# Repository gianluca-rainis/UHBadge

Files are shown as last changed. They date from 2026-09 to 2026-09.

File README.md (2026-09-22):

# UHBadge





View PCB (https://kicanvas.org/?repo=https://github.com/gianluca-rainis/UHBadge)

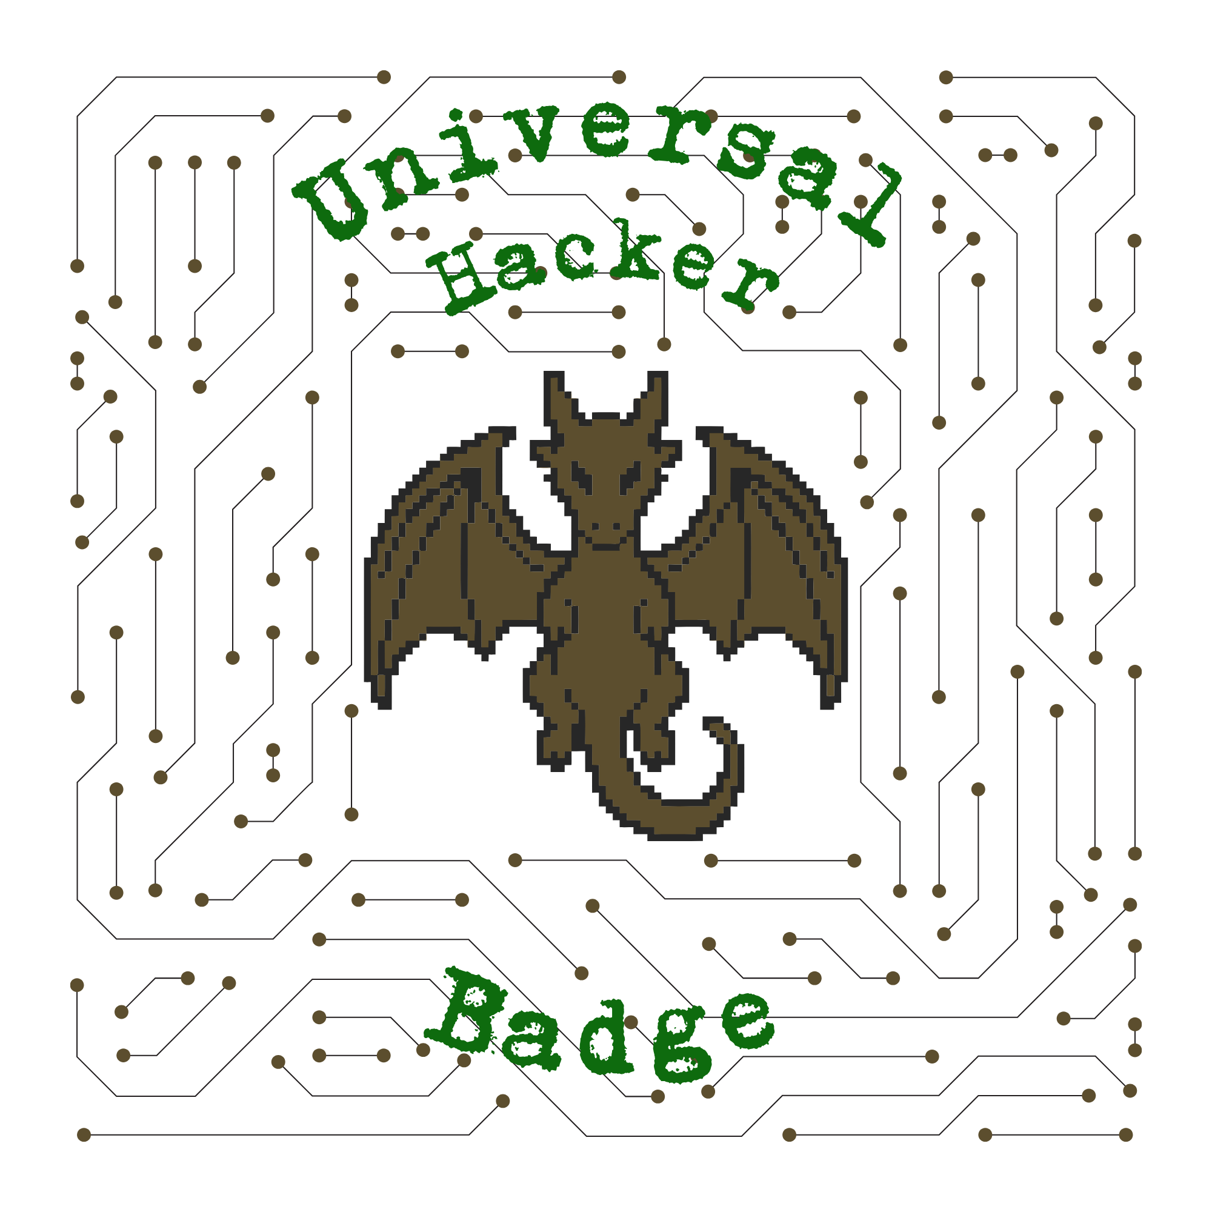
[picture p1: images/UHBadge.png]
UHBadge Logo


Universal Hacker Badge - The ultimate badge for hackers.

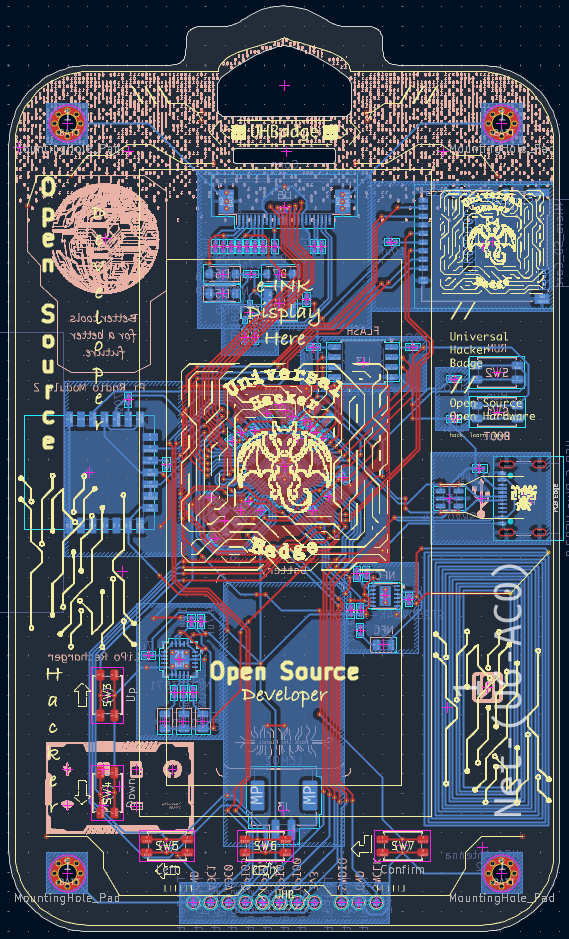
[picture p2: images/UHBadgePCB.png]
UHBadge PCB Image


## Author
The author of the whole project is: 
**Gianluca Rainis** - [gianluca-rainis](https://github.com/gianluca-rainis) on GitHub.

## License
### Hardware design files (schematics, PCB, BOM):
Licensed under [CERN-OHL-S v2.0](LICENSE-CERN-OHL-S.md)

### Software, firmware and documentation:
Licensed under the [MIT License](LICENSE-MIT.md)

## AI Disclaimer
**No AI was used in the conception, design, or engineering of the hardware.**
Every circuit and every design decision are the original work of the author.

*AI tools* were used as **writing assistants** for parts of the firmware, to help write technical drivers and low-level functions.
**All content has been reviewed, verified, and edited by the author.**

## Development Tools
- **PCB Design:** KiCad
- **Documentation and code:** Visual Studio Code

## PCB Manufacturing
The Gerber files for PCB manufacturing are available in the [`gerber/`](gerber/) directory.

## Project Structure
```
UHBadge/
├── CustomFootprints.pretty/  # Custom footprints
├── firmware/                 # The RP2350 firmware
├── gerber/                   # PCB manufacturing files (Gerber format)
├── images/                   # Documentation images
├── .gitattributes            # Gitattributes file
├── .gitignore                # Gitignore file
├── gerber.zip                # Zip folder with all the gerber files
├── UHBadge.kicad_pcb         # PCB layout file
├── UHBadge.kicad_pro         # KiCad project file
├── UHBadge.kicad_sch         # Schematic file
├── UHBadge.step              # 3D model
├── BOM.csv                   # Bill Of Materials
├── LICENSE-CERN-OHL-S.md     # CERN-OHL-S License
├── LICENSE-MIT.md            # MIT License
└── README.md                 # This file
```

## Technical Details
- **Size**: 70mm x 117.6mm
- **Layers**: 2
- **Supply Voltage**: 3v3

## Build the firmware
From the directory of the repo:
```bash
cd firmware/build

cmake ..
make -j$(sysctl -n hw.ncpu)
```

You'll find the `UHBadge.uf2` file in the `firmware/build` directory.

## Hardware
### Schematic
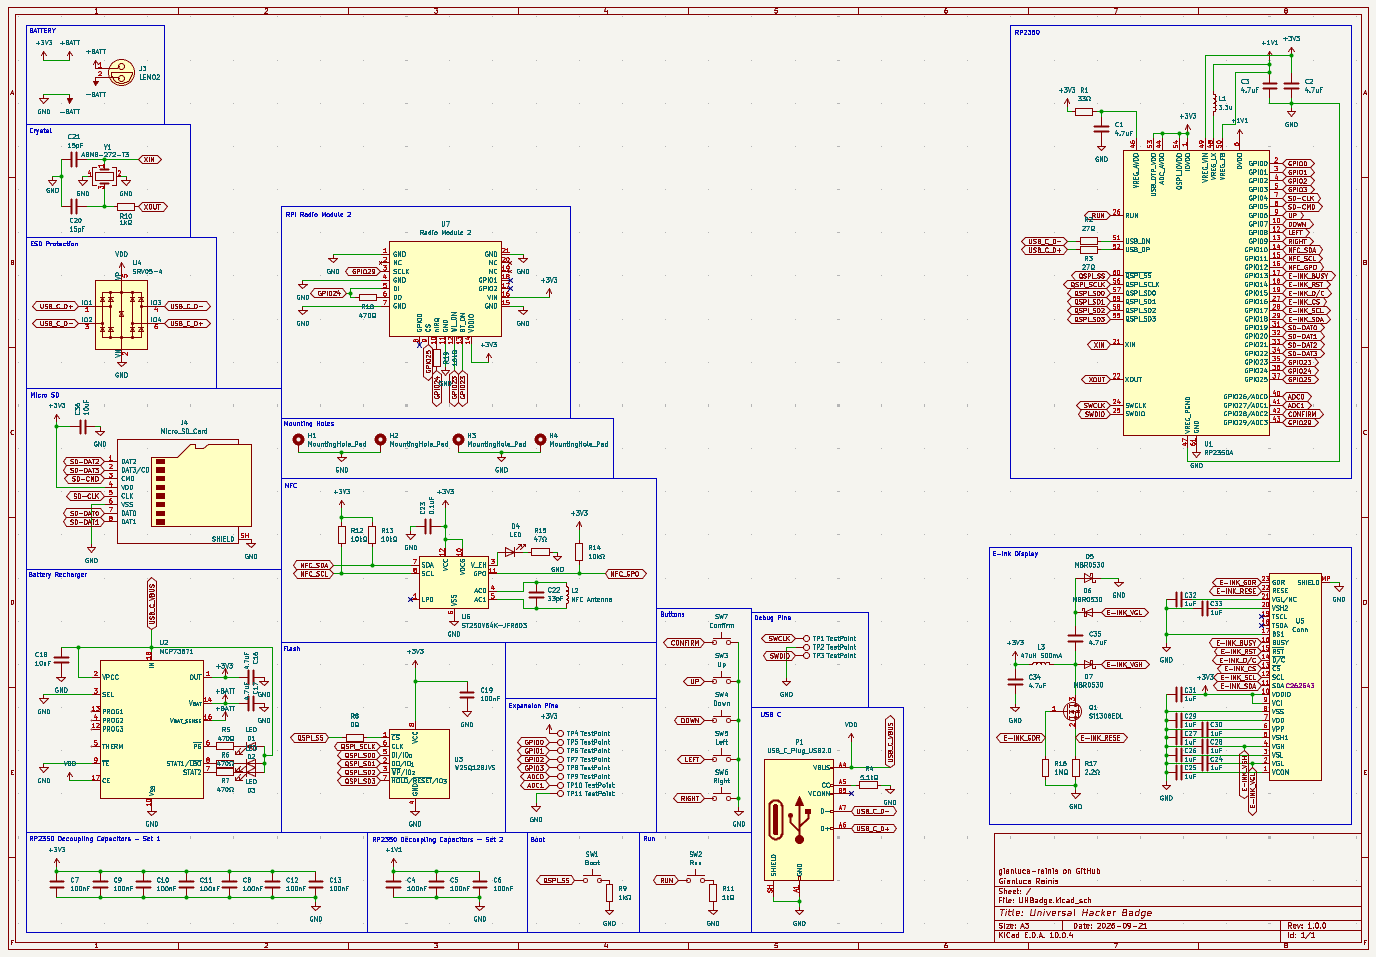
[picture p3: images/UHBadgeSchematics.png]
UHBadge Schematics


### PCB
UHBadge PCB Image

### 3D Render
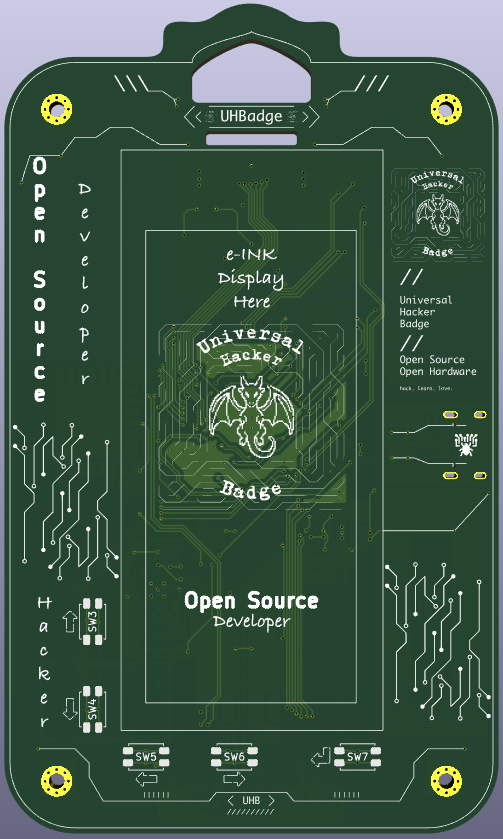
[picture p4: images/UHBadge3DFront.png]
UHBadge Render Front

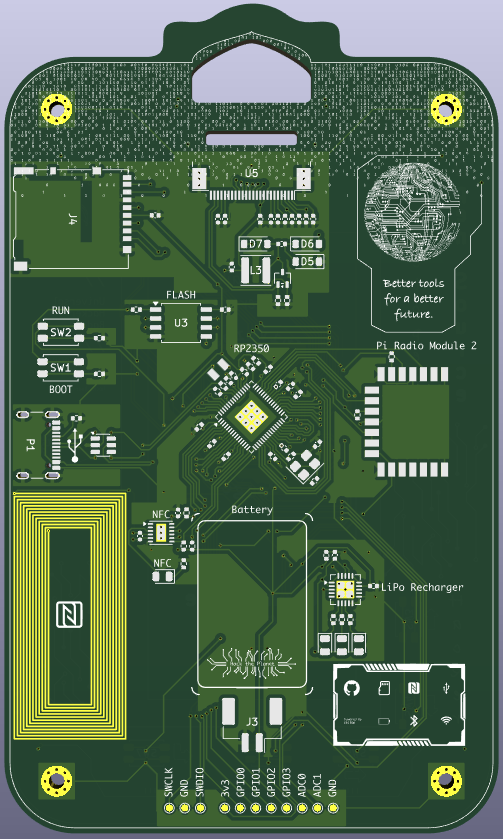
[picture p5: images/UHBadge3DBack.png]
UHBadge Render Back


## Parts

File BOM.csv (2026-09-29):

Reference | Quantity | Value | Footprint | Total Price | LCSC Part
C1,C2,C3,C16,C17,C34,C35 | 7 | 4.7uF | Capacitor_SMD:C_0402_1005Metric | $0.85 | C368809
C4,C5,C6,C7,C8,C9,C10,C11,C12,C13,C19 | 11 | 100nF | Capacitor_SMD:C_0402_1005Metric | $0.46 | C1525
C18,C36 | 2 | 10uF | Capacitor_SMD:C_0402_1005Metric | $0.65 | C315248
C20,C21 | 2 | 15pF | Capacitor_SMD:C_0402_1005Metric | $0.36 | C1548
C22 | 1 | 33pF | Capacitor_SMD:C_0402_1005Metric | $0.43 | C70465
C23 | 1 | 0.1uF | Capacitor_SMD:C_0402_1005Metric | $0.46 | C1525
C24,C25,C26,C27,C28,C29,C30,C31,C32,C33 | 10 | 1uF | Capacitor_SMD:C_0402_1005Metric | $0.50 | C52923
D1,D2,D3,D4 | 4 | LED | LED_SMD:LED_0805_2012Metric | $0.50 | C25170728
D5,D6,D7 | 3 | MBR0530 | Diode_SMD:D_SOD-123 | $0.89 | C725477
J3 | 1 | LEMO2 | Connector_Molex:Molex_CLIK-Mate_502494-0270_1x02-1MP_P2.00mm_Horizontal | $0.56 | C587928
J4 | 1 | Micro_SD_Card | Connector_Card:microSD_HC_Hirose_DM3AT-SF-PEJM5 | $1.79 | C114218
L1 | 1 | 3.3u | CustomFootprints:Inductor | $1.43 | C42411119
L3 | 1 | 47uH 500mA | Inductor_SMD:L_APV_ANR4018 | $0.79 | C167808
P1 | 1 | USB_C_Plug_USB2.0 | Connector_USB:USB_C_Receptacle_GCT_USB4105-xx-A_16P_TopMnt_Horizontal | $1.31 | C3020560
Q1 | 1 | Si1308EDL | Package_TO_SOT_SMD:SOT-323_SC-70 | $0.43 | C7603347
R1 | 1 | 33Ω | Resistor_SMD:R_0402_1005Metric | $0.18 | C453643
R2,R3 | 2 | 27Ω | Resistor_SMD:R_0402_1005Metric | $0.20 | C2909343
R4 | 1 | 5.1kΩ | Resistor_SMD:R_0402_1005Metric | $0.19 | C2906874
R5,R6,R7,R18 | 4 | 470Ω | Resistor_SMD:R_0402_1005Metric | $0.26 | C25117
R8 | 1 | 0Ω | Resistor_SMD:R_0402_1005Metric | $0.36 | C106231
R9,R10,R11 | 3 | 1kΩ | Resistor_SMD:R_0402_1005Metric | $0.22 | C11702
R12,R13,R14,R19 | 4 | 10kΩ | Resistor_SMD:R_0402_1005Metric | $0.19 | C71617
R15 | 1 | 47Ω | Resistor_SMD:R_0402_1005Metric | $0.18 | C2909362
R16 | 1 | 1MΩ | Resistor_SMD:R_0402_1005Metric | $0.26 | C93949
R17 | 1 | 2.2Ω | Resistor_SMD:R_0402_1005Metric | $0.20 | C2906903
SW1 | 1 | Boot | Button_Switch_SMD:SW_SPST_EVQP2_MiddlePushTravel_H2.5mm | $0.29 | C2915174
SW2 | 1 | Run | Button_Switch_SMD:SW_SPST_EVQP2_MiddlePushTravel_H2.5mm | $0.29 | C2915174
SW3 | 1 | Up | Button_Switch_SMD:SW_SPST_EVQP2_MiddlePushTravel_H2.5mm | $0.29 | C2915174
SW4 | 1 | Down | Button_Switch_SMD:SW_SPST_EVQP2_MiddlePushTravel_H2.5mm | $0.29 | C2915174
SW5 | 1 | Left | Button_Switch_SMD:SW_SPST_EVQP2_MiddlePushTravel_H2.5mm | $0.29 | C2915174
SW6 | 1 | Right | Button_Switch_SMD:SW_SPST_EVQP2_MiddlePushTravel_H2.5mm | $0.29 | C2915174
SW7 | 1 | Confirm | Button_Switch_SMD:SW_SPST_EVQP2_MiddlePushTravel_H2.5mm | $0.29 | C2915174
U1 | 1 | RP2350A | Package_DFN_QFN:QFN-60-1EP_7x7mm_P0.4mm_EP3.4x3.4mm | $1.30 | C42411118
U2 | 1 | MCP73871 | Package_DFN_QFN:QFN-20-1EP_4x4mm_P0.5mm_EP2.5x2.5mm | $2.20 | C511310
U3 | 1 | W25Q128JVS | Package_SO:SOIC-8_5.3x5.3mm_P1.27mm | $2.53 | C113767
U4 | 1 | SRV05-4 | Package_TO_SOT_SMD:SOT-23-6 | $0.56 | C2836319
U5 | 1 | Conn | Connector_FFC-FPC:Jushuo_AFC07-S24FCA-00_1x24-1MP_P0.50_Horizontal | $0.66 | C262567
U6 | 1 | ST25DV64K-JFR6D3 | Package_DFN_QFN:ST_UFDFPN-12-1EP_3x3mm_P0.5mm_EP1.4x2.55mm | $2.11 | C2654868
U7 | 1 | Radio Module 2 | CustomFootprints:rpi_rmc20452t | 4.20€ (~ $4.76) | https://www.reichelt.com/it/it/shop/prodotto/raspberry_pi_-_modulo_radio_rmc20452t-407167
Y1 | 1 | ABM8-272-T3 | Crystal:Crystal_SMD_3225-4Pin_3.2x2.5mm | $0.32 | C19270184
e-ink display | 1 |  |  | 9.39€ (~ $10.64) | https://it.aliexpress.com/item/1005012065049246.html
Li-Po battery | 1 |  |  | 7.44€ (~ $8.43) | https://it.aliexpress.com/item/1005007341161722.html
Total | $49.19

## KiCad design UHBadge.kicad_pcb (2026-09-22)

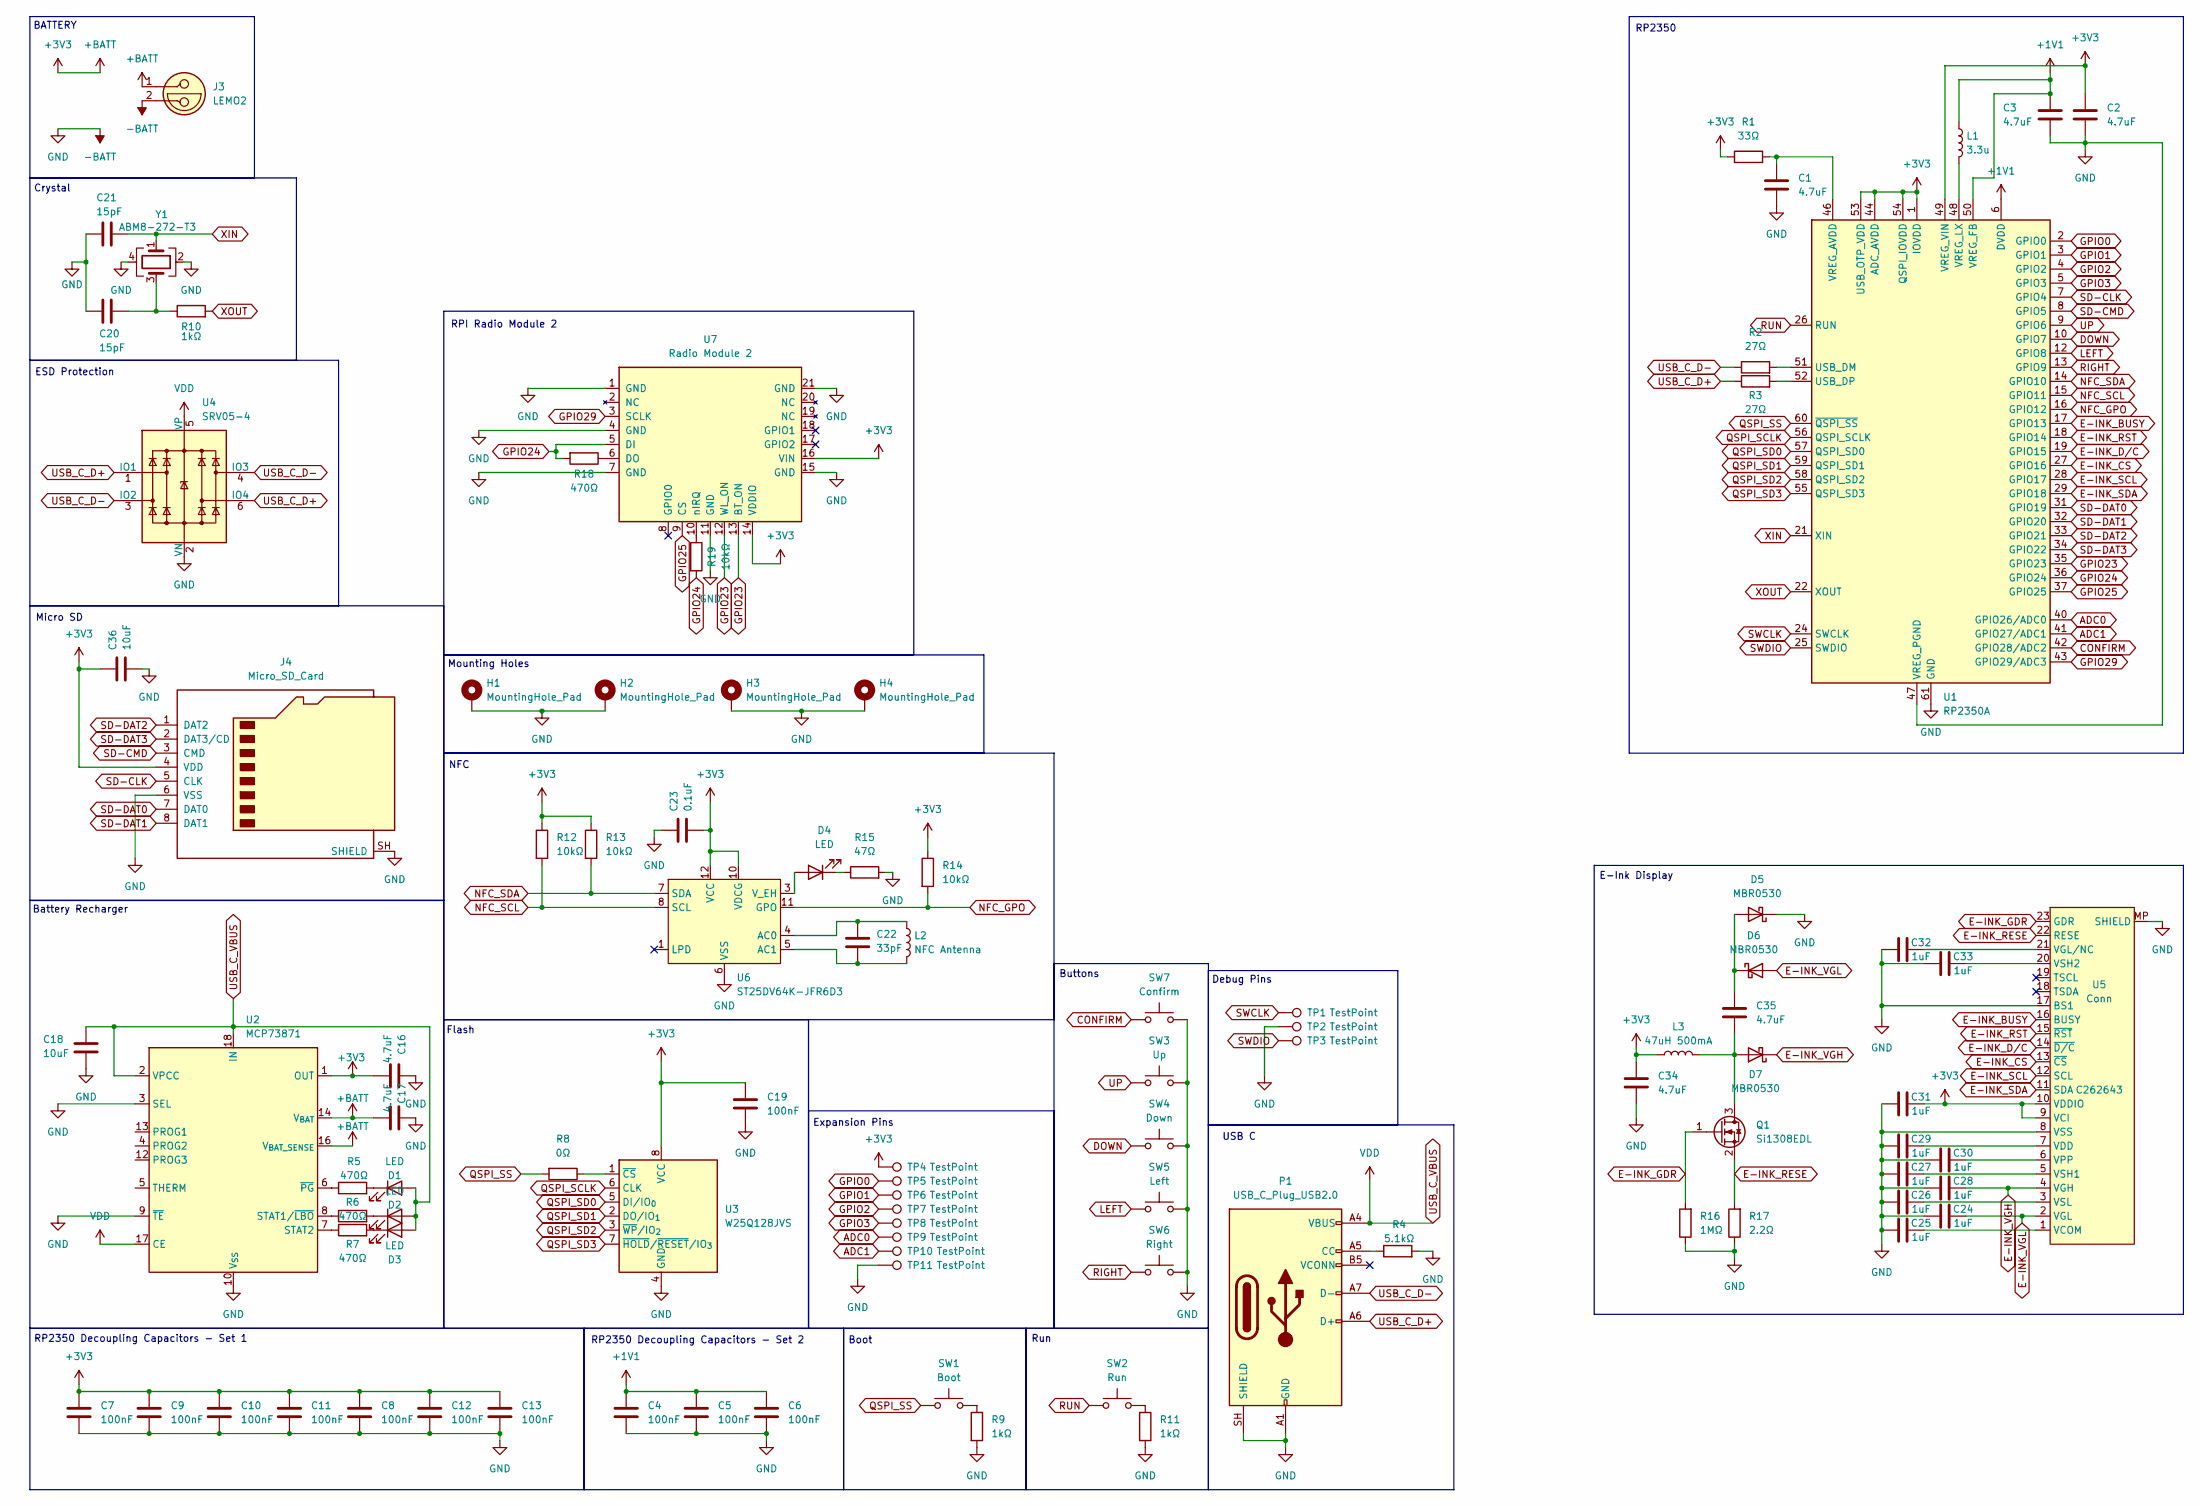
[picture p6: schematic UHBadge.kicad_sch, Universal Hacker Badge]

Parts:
C1, C2, C3, C16, C17, C34, C35: 4.7uF; C_0402_1005Metric
C4, C5, C6, C7, C8, C9, C10, C11, C12, C13, C19: 100nF; C_0402_1005Metric
C18, C36: 10uF; C_0402_1005Metric
C20, C21: 15pF; C_0402_1005Metric
C22: 33pF; C_0402_1005Metric
C23: 0.1uF; C_0402_1005Metric
C24, C25, C26, C27, C28, C29, C30, C31, C32, C33: 1uF; C_0402_1005Metric
D1, D2, D3, D4: LED; LED_0805_2012Metric
D5, D6, D7: MBR0530; D_SOD-123
H1, H2, H3, H4: MountingHole_Pad; MountingHole_2.2mm_M2_Pad_Via
J3: LEMO2; Molex_CLIK-Mate_502494-0270_1x02-1MP_P2.00mm_Horizontal
J4: Micro_SD_Card; microSD_HC_Hirose_DM3AT-SF-PEJM5
L1: 3.3u; Inductor
L2: NFC Antenna; NFC_Antenna
L3: 47uH 500mA; L_APV_ANR4018
P1: USB_C_Plug_USB2.0; USB_C_Receptacle_GCT_USB4105-xx-A_16P_TopMnt_Horizontal
Q1: Si1308EDL; SOT-323_SC-70
R1: 33Ω; R_0402_1005Metric
R2, R3: 27Ω; R_0402_1005Metric
R4: 5.1kΩ; R_0402_1005Metric
R5, R6, R7, R18: 470Ω; R_0402_1005Metric
R8: 0Ω; R_0402_1005Metric
R9, R10, R11: 1kΩ; R_0402_1005Metric
R12, R13, R14, R19: 10kΩ; R_0402_1005Metric
R15: 47Ω; R_0402_1005Metric
R16: 1MΩ; R_0402_1005Metric
R17: 2.2Ω; R_0402_1005Metric
SW1: Boot; SW_SPST_EVQP2_MiddlePushTravel_H2.5mm
SW2: Run; SW_SPST_EVQP2_MiddlePushTravel_H2.5mm
SW3: Up; SW_SPST_EVQP2_MiddlePushTravel_H2.5mm
SW4: Down; SW_SPST_EVQP2_MiddlePushTravel_H2.5mm
SW5: Left; SW_SPST_EVQP2_MiddlePushTravel_H2.5mm
SW6: Right; SW_SPST_EVQP2_MiddlePushTravel_H2.5mm
SW7: Confirm; SW_SPST_EVQP2_MiddlePushTravel_H2.5mm
TP1, TP2, TP3, TP4, TP5, TP6, TP7, TP8, TP9, TP10, TP11: TestPoint; TestPoint_Pad_D1.0mm
U1: RP2350A; QFN-60-1EP_7x7mm_P0.4mm_EP3.4x3.4mm
U2: MCP73871; QFN-20-1EP_4x4mm_P0.5mm_EP2.5x2.5mm
U3: W25Q128JVS; SOIC-8_5.3x5.3mm_P1.27mm
U4: SRV05-4; SOT-23-6
U5: Conn; Jushuo_AFC07-S24FCA-00_1x24-1MP_P0.50_Horizontal; LCSC Part # C262643
U6: ST25DV64K-JFR6D3; ST_UFDFPN-12-1EP_3x3mm_P0.5mm_EP1.4x2.55mm
U7: Radio Module 2; rpi_rmc20452t
Y1: ABM8-272-T3; Crystal_SMD_3225-4Pin_3.2x2.5mm; LCSC Part # C20625731

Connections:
+1V1: C3.1, C4.1, C5.1, C6.1, L1.1, U1.6 (DVDD), U1.23 (DVDD), U1.39 (DVDD), U1.50 (VREG_FB)
+3V3: C2.1, C7.1, C8.1, C9.1, C10.1, C11.1, C12.1, C13.1, C16.2, C17.2, C19.1, C23.2, C31.2, C34.1, C36.1, J3.1, J4.4 (VDD), L3.1, R1.1, R12.1, R13.1, R14.1, TP4.1 (1_1), U1.1 (IOVDD), U1.11 (IOVDD), U1.20 (IOVDD), U1.30 (IOVDD), U1.38 (IOVDD), U1.44 (ADC_AVDD), U1.45 (IOVDD), U1.49 (VREG_VIN), U1.53 (USB_OTP_VDD), U1.54 (QSPI_IOVDD), U2.1 (OUT), U2.14 (V_{BAT}), U2.15 (V_{BAT}), U2.16 (V_{BAT_SENSE}), U2.20 (OUT), U3.8 (VCC), U5.9 (VCI), U5.10 (VDDIO), U6.10 (VDCG), U6.12 (VCC), U7.14 (VDDIO), U7.16 (VIN)
-BATT: C1.2, C2.2, C3.2, C4.2, C5.2, C6.2, C7.2, C8.2, C9.2, C10.2, C11.2, C12.2, C13.2, C16.1, C17.1, C18.2, C19.2, C20.2, C21.1, C23.1, C24.1, C25.1, C26.1, C27.1, C28.1, C29.1, C30.1, C31.1, C32.1, C33.1, C34.2, C36.2, D5.1 (K), H1.1 (1_1), H2.1 (1_1), H3.1 (1_1), H4.1 (1_1), J3.2, J4.6 (VSS), J4.SH (SHIELD), P1.A1 (GND), P1.A12 (GND), P1.B1 (GND), P1.B12 (GND), P1.SH (SHIELD), R4.2, R9.2, R11.2, R15.2, R16.1, R17.1, SW3.2, SW4.2, SW5.2, SW6.2, SW7.2, TP2.1 (1_1), TP11.1 (1_1), U1.47 (VREG_PGND), U1.61 (GND), U2.3 (SEL), U2.9 (~TE), U2.10 (V_{SS}), U2.11 (V_{SS}), U2.21 (V_{SS}), U3.4 (GND), U4.2 (VN), U5.8 (VSS), U5.17 (BS1), U5.MP (SHIELD), U6.6 (VSS), U7.1 (GND), U7.4 (GND), U7.7 (GND), U7.11 (GND), U7.15 (GND), U7.21 (GND), Y1.2, Y1.4
ADC0: TP9.1 (1_1), U1.40 (GPIO26/ADC0)
ADC1: TP10.1 (1_1), U1.41 (GPIO27/ADC1)
CONFIRM: SW7.1, U1.42 (GPIO28/ADC2)
DOWN: SW4.1, U1.10 (GPIO7)
E-INK_BUSY: U1.17 (GPIO13), U5.16 (BUSY)
E-INK_CS: U1.27 (GPIO16), U5.13 (~CS)
E-INK_D/C: U1.19 (GPIO15), U5.14 (~D/C)
E-INK_GDR: Q1.1 (G), R16.2, U5.23 (GDR)
E-INK_RESE: Q1.2 (S), R17.2, U5.22 (RESE)
E-INK_RST: U1.18 (GPIO14), U5.15 (~RST)
E-INK_SCL: U1.28 (GPIO17), U5.12 (SCL)
E-INK_SDA: U1.29 (GPIO18), U5.11 (SDA)
E-INK_VGH: C28.2, D7.1 (K), U5.4 (VGH)
E-INK_VGL: C24.2, D6.2 (A), U5.2 (VGL)
GPIO0: TP5.1 (1_1), U1.2 (GPIO0)
GPIO1: TP6.1 (1_1), U1.3 (GPIO1)
GPIO2: TP7.1 (1_1), U1.4 (GPIO2)
GPIO3: TP8.1 (1_1), U1.5 (GPIO3)
GPIO23: U1.35 (GPIO23), U7.12 (WL_ON), U7.13 (BT_ON)
GPIO24: R18.2, R19.2, U1.36 (GPIO24), U7.5 (DI)
GPIO25: U1.37 (GPIO25), U7.9 (CS)
GPIO29: U1.43 (GPIO29/ADC3), U7.3 (SCLK)
LEFT: SW5.1, U1.12 (GPIO8)
NFC_GPO: R14.2, U1.16 (GPIO12), U6.11 (GPO)
NFC_SCL: R12.2, U1.15 (GPIO11), U6.8 (SCL)
NFC_SDA: R13.2, U1.14 (GPIO10), U6.7 (SDA)
unnamed: C20.1, R10.1, Y1.3
unnamed: D1.1 (K), R5.2
unnamed: D2.1 (K), R6.2
unnamed: D3.1 (K), R7.2
unnamed: D4.2 (A), U6.3 (V_EH)
unnamed: D4.1 (K), R15.1
unnamed: C35.1, D5.2 (A), D6.1 (K)
unnamed: C35.2, D7.2 (A), L3.2, Q1.3 (D)
unnamed: P1.A5 (CC), R4.1
unnamed: R9.1, SW1.2
unnamed: R11.1, SW2.2
unnamed: R2.2, U1.51 (USB_DM)
unnamed: R3.2, U1.52 (USB_DP)
unnamed: C1.1, R1.2, U1.46 (VREG_AVDD)
unnamed: L1.2, U1.48 (VREG_LX)
unnamed: R6.1, U2.8 (STAT1/~LBO)
unnamed: R7.1, U2.7 (STAT2)
unnamed: R5.1, U2.6 (~PG)
unnamed: R8.1, U3.1 (~CS)
unnamed: C25.2, U5.1 (VCOM)
unnamed: C29.2, U5.7 (VDD)
unnamed: C32.2, U5.21 (VGL/NC)
unnamed: C30.2, U5.6 (VPP)
unnamed: C27.2, U5.5 (VSH1)
unnamed: C33.2, U5.20 (VSH2)
unnamed: C26.2, U5.3 (VSL)
unnamed: C22.1, L2.1, U6.4 (AC0)
unnamed: C22.2, L2.2, U6.5 (AC1)
unnamed: R18.1, U7.6 (DO)
unnamed: R19.1, U7.10 (nIRQ)
QSPI_SCLK: U1.56 (QSPI_SCLK), U3.6 (CLK)
QSPI_SD0: U1.57 (QSPI_SD0), U3.5 (DI/IO_{0})
QSPI_SD1: U1.59 (QSPI_SD1), U3.2 (DO/IO_{1})
QSPI_SD2: U1.58 (QSPI_SD2), U3.3 (~WP/IO_{2})
QSPI_SD3: U1.55 (QSPI_SD3), U3.7 (~HOLD/~RESET/IO_{3})
QSPI_SS: R8.2, SW1.1, U1.60 (~QSPI_SS)
RIGHT: SW6.1, U1.13 (GPIO9)
RUN: SW2.1, U1.26 (RUN)
SD-CLK: J4.5 (CLK), U1.7 (GPIO4)
SD-CMD: J4.3 (CMD), U1.8 (GPIO5)
SD-DAT0: J4.7 (DAT0), U1.31 (GPIO19)
SD-DAT1: J4.8 (DAT1), U1.32 (GPIO20)
SD-DAT2: J4.1 (DAT2), U1.33 (GPIO21)
SD-DAT3: J4.2 (DAT3/CD), U1.34 (GPIO22)
SWCLK: TP1.1 (1_1), U1.24 (SWCLK)
SWDIO: TP3.1 (1_1), U1.25 (SWDIO)
UP: SW3.1, U1.9 (GPIO6)
USB_C_D+: P1.A6 (D+), R3.1, U4.1 (IO1), U4.6 (IO4)
USB_C_D-: P1.A7 (D-), R2.1, U4.3 (IO2), U4.4 (IO3)
USB_C_VBUS: C18.1, D1.2 (A), D2.2 (A), D3.2 (A), P1.A4 (VBUS), P1.A9 (VBUS), P1.B4 (VBUS), P1.B9 (VBUS), U2.2 (VPCC), U2.17 (CE), U2.18 (IN), U2.19 (IN), U4.5 (VP)
XIN: C21.2, U1.21 (XIN), Y1.1
XOUT: R10.2, U1.22 (XOUT)

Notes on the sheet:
USB C
NFC
Mounting Holes
Expansion Pins
Boot
Flash
Micro SD
RP2350 Decoupling Capacitors - Set 1
Debug Pins
RPI Radio Module 2
Battery Recharger
RP2350 Decoupling Capacitors - Set 2
BATTERY
Buttons
Crystal
ESD Protection
Run
E-Ink Display
RP2350

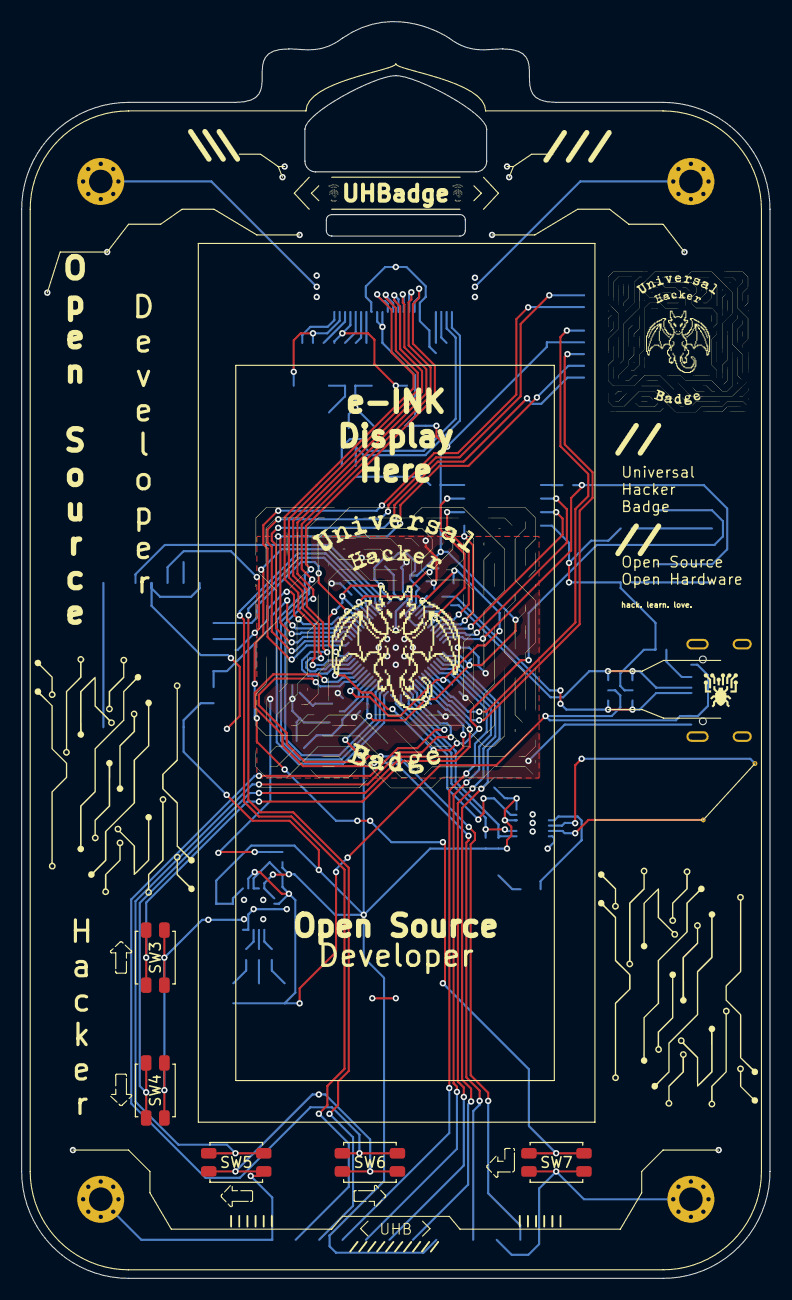
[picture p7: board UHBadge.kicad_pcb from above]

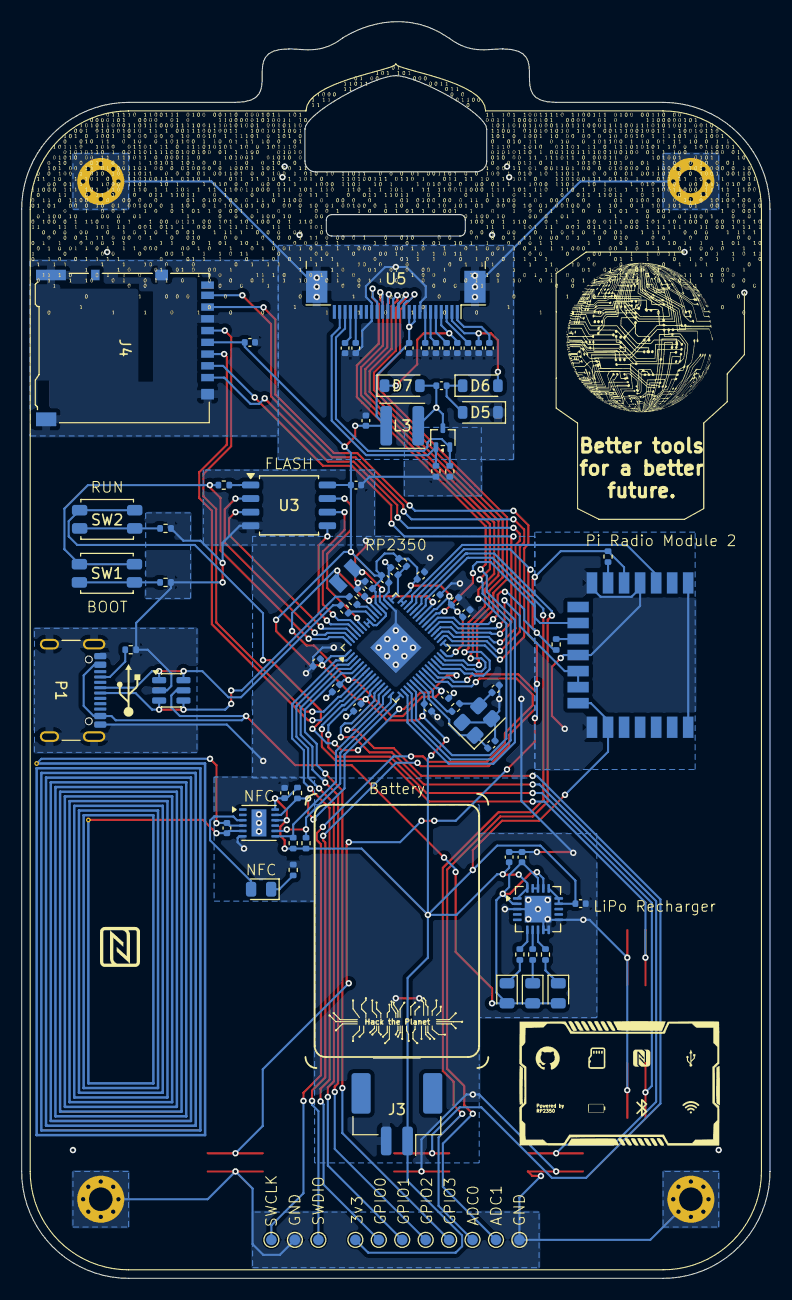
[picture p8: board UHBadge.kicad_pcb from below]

Board: 2 copper layers, 70.0 x 117.6 mm, 97 parts (88 on the bottom side), 81 nets.

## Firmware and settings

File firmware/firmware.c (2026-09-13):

#include "firmware.h"
#include "ui/eink.h"
#include "ui/ui.h"
#include "hardware/gpio.h"
#include "pico/stdlib.h"

#include <stdlib.h>

/* 
    This function is runned only once at the start of the program.
*/
void setup() {
    // Initialize the GPIO pins
    gpio_init(GPIO_SD_CLK);
    gpio_set_dir(GPIO_SD_CLK, GPIO_OUT);
    gpio_init(GPIO_SD_CMD);
    gpio_set_dir(GPIO_SD_CMD, GPIO_OUT);

    gpio_init(GPIO_UP);
    gpio_set_dir(GPIO_UP, GPIO_IN);
    gpio_pull_up(GPIO_UP);
    gpio_init(GPIO_DOWN);
    gpio_set_dir(GPIO_DOWN, GPIO_IN);
    gpio_pull_up(GPIO_DOWN);
    gpio_init(GPIO_LEFT);
    gpio_set_dir(GPIO_LEFT, GPIO_IN);
    gpio_pull_up(GPIO_LEFT);
    gpio_init(GPIO_RIGHT);
    gpio_set_dir(GPIO_RIGHT, GPIO_IN);
    gpio_pull_up(GPIO_RIGHT);

    gpio_init(GPIO_NFC_SDA);
    gpio_set_dir(GPIO_NFC_SDA, GPIO_IN);
    gpio_init(GPIO_NFC_SCL);
    gpio_set_dir(GPIO_NFC_SCL, GPIO_IN);
    gpio_init(GPIO_NFC_GPO);
    gpio_set_dir(GPIO_NFC_GPO, GPIO_IN);

    gpio_init(GPIO_E_INK_BUSY);
    gpio_set_dir(GPIO_E_INK_BUSY, GPIO_IN);
    gpio_init(GPIO_E_INK_RST);
    gpio_set_dir(GPIO_E_INK_RST, GPIO_OUT);
    gpio_init(GPIO_E_INK_DC);
    gpio_set_dir(GPIO_E_INK_DC, GPIO_OUT);
    gpio_init(GPIO_E_INK_CS);
    gpio_set_dir(GPIO_E_INK_CS, GPIO_OUT);
    gpio_init(GPIO_E_INK_SCL);
    gpio_set_dir(GPIO_E_INK_SCL, GPIO_OUT);
    gpio_init(GPIO_E_INK_SDA);
    gpio_set_dir(GPIO_E_INK_SDA, GPIO_OUT);

    gpio_init(GPIO_SD_DAT0);
    gpio_set_dir(GPIO_SD_DAT0, GPIO_IN);
    gpio_init(GPIO_SD_DAT1);
    gpio_set_dir(GPIO_SD_DAT1, GPIO_IN);
    gpio_init(GPIO_SD_DAT2);
    gpio_set_dir(GPIO_SD_DAT2, GPIO_IN);
    gpio_init(GPIO_SD_DAT3);
    gpio_set_dir(GPIO_SD_DAT3, GPIO_IN);

    gpio_init(GPIO_PI_RADIO_MODULE_WLON_BTON);
    gpio_set_dir(GPIO_PI_RADIO_MODULE_WLON_BTON, GPIO_OUT);
    gpio_init(GPIO_PI_RADIO_MODULE_DI_DO_NIRQ);
    gpio_set_dir(GPIO_PI_RADIO_MODULE_DI_DO_NIRQ, GPIO_IN);
    gpio_init(GPIO_PI_RADIO_MODULE_CS);
    gpio_set_dir(GPIO_PI_RADIO_MODULE_CS, GPIO_OUT);

    gpio_init(GPIO_PI_RADIO_MODULE_SCLK);
    gpio_set_dir(GPIO_PI_RADIO_MODULE_SCLK, GPIO_OUT);

    // Expansion pins - decomment for use. Should be commented if not used.
    /* 
        * gpio_init(GPIO_EXPANSION_1);
        * gpio_set_dir(GPIO_EXPANSION_1, GPIO_OUT);
        * gpio_init(GPIO_EXPANSION_2);
        * gpio_set_dir(GPIO_EXPANSION_2, GPIO_OUT);
        * gpio_init(GPIO_EXPANSION_3);
        * gpio_set_dir(GPIO_EXPANSION_3, GPIO_OUT);
        * gpio_init(GPIO_EXPANSION_4);
        * gpio_set_dir(GPIO_EXPANSION_4, GPIO_OUT);
        * gpio_init(GPIO_EXPANSION_ADC0);
        * gpio_set_dir(GPIO_EXPANSION_ADC0, GPIO_IN);
        * gpio_init(GPIO_EXPANSION_ADC1);
        * gpio_set_dir(GPIO_EXPANSION_ADC1, GPIO_IN);
    */

    // Unconnected pins - decomment for nothing. Should be commented if not used (always, you can't use it).
    /* 
        * gpio_init(GPIO_UNCONNECTED_ADC2);
        * gpio_set_dir(GPIO_UNCONNECTED_ADC2, GPIO_IN);
    */

    einkInit();
    einkClear();

    uiInit();
}

/* 
    This function is runned in a loop after the setup function.
*/
void loop() {
    uiUpdate();

    sleep_ms(20);
}

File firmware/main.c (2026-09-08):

/* 
    * Pinout:
    * 
    * GPIO0 - Expansion Pin
    * GPIO1 - Expansion Pin
    * GPIO2 - Expansion Pin
    * GPIO3 - Expansion Pin
    * GPIO4 - SD CLK
    * GPIO5 - SD CMD
    * GPIO6 - UP
    * GPIO7 - DOWN
    * GPIO8 - LEFT
    * GPIO9 - RIGHT
    * GPIO10 - NFC SDA
    * GPIO11 - NFC SCL
    * GPIO12 - NFC GPO
    * GPIO13 - E-INK BUSY
    * GPIO14 - E-INK RST
    * GPIO15 - E-INK D/C
    * GPIO16 - E-INK CS
    * GPIO17 - E-INK SCL
    * GPIO18 - E-INK SDA
    * GPIO19 - SD DAT0
    * GPIO20 - SD DAT1
    * GPIO21 - SD DAT2
    * GPIO22 - SD DAT3
    * GPIO23 - Pi Radio Module WL_ON + BT_ON
    * GPIO24 - Pi Radio Module DI + DO + nIRQ
    * GPIO25 - Pi Radio Module CS
    * GPIO26/ADC0 - Expansion Pin
    * GPIO27/ADC1 - Expansion Pin
    * GPIO28/ADC2 - UNCONNECTED
    * GPIO29/ADC3 - Pi Radio Module SCLK
*/

#include "firmware.h"
#include <stdbool.h>

int main() {
    setup();

    while (true)
    {
        loop();
    }

    return 0;
}

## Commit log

2026-08-15 Created the KiCad project.
    [UHBadge.kicad_pcb, UHBadge.kicad_sch]
2026-08-16 Added the RP2350. Added the USB-C. Added the battery. Started working on the recharge system.
    [UHBadge.kicad_sch]
2026-08-19 Added the flash, fixed the RP2350 main connections.
    [UHBadge.kicad_sch]
2026-08-19 Added esd protection.
    [UHBadge.kicad_sch]
2026-08-19 Added the e-ink display.
    [UHBadge.kicad_sch]
2026-08-20 Added RP2350 expansion GPIO pins.
    [UHBadge.kicad_sch]
2026-08-23 Added footprints.
    [UHBadge.kicad_pcb, UHBadge.kicad_sch]
2026-08-27 Created the Badge borders. Fixed the buttons footprints.
    [UHBadge.kicad_pcb, UHBadge.kicad_sch]
2026-08-27 Connected the buttons to the RP2350.
    [UHBadge.kicad_pcb, UHBadge.kicad_sch]
2026-08-28 Added the e-ink display. Made the button design.
    [UHBadge.kicad_pcb, UHBadge.kicad_sch]
2026-08-31 Connected the support components to the e-ink display. Placed the RP2350 and started connecting the support components.
    [UHBadge.kicad_pcb, UHBadge.kicad_sch]
2026-09-02 RP2350 Support components placement, USB-C connection and NFC component placement.
    [UHBadge.kicad_pcb, UHBadge.kicad_sch]
2026-09-02 Battery Port Placement. Finished the recharge system. Placed the mounting holes. Started filling the areas and connecting the components.
    [UHBadge.kicad_pcb, UHBadge.kicad_sch]
2026-09-03 Connected the components together.
    [UHBadge.kicad_pcb]
2026-09-04 Fixed the position of the GPIO and SWD pins.
    [UHBadge.kicad_pcb]
2026-09-04 UHBadge - Finished the connections between the components.
    [UHBadge.kicad_pcb]
2026-09-05 Added two new mounting holes. Fixed the NFC footprint. Started working on the design.
    [UHBadge.kicad_pcb, UHBadge.kicad_sch]
2026-09-06 Remade the whole design.
    [UHBadge.kicad_pcb]
2026-09-07 Added the Pi Radio Module 2.
    [UHBadge.kicad_pcb, UHBadge.kicad_sch]
2026-09-08 Added the microSD card slot. Moved the SW pins. Removed two expansion pins. Added some graphical designs.
    [UHBadge.kicad_pcb, UHBadge.kicad_sch]
2026-09-09 Fixed some little graphical details.
    [UHBadge.kicad_pcb]
2026-09-10 Finished the connections. Made some graphics.
    [UHBadge.kicad_pcb]
2026-09-11 Finished the design.
    [UHBadge.kicad_pcb]
2026-09-13 Fixed the eink driver.
    [eink.c, eink.h, firmware.c]
2026-09-13 Build the firmware for the first time. Fixed some bugs.
    [eink.c]
2026-09-13 Created the gerber files.
    [UHBadge-B_Cu.gbr, UHBadge-B_Mask.gbr, UHBadge-B_Paste.gbr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]
2026-09-13 Fixed a graphical detail. Rebuild the gerber files.
    [UHBadge-B_Cu.gbr, UHBadge-B_Mask.gbr, UHBadge-B_Paste.gbr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]
2026-09-16 Started writing the wifi driver.
2026-09-17 Added the BLE support. Fixed some details.
    [eink.c]
2026-09-21 Added confirm button. Moved the NFC tag. Fixed the design.
    [UHBadge.kicad_pcb, UHBadge.kicad_sch]
2026-09-22 Fixed the routes.
    [UHBadge.kicad_pcb]
2026-09-22 Rebuild the gerber files.
    [UHBadge-B_Cu.gbr, UHBadge-B_Mask.gbr, UHBadge-B_Paste.gbr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]
2026-09-22 Fixed a detail. Rebuild the gerber files.
    [UHBadge-B_Cu.gbr, UHBadge-B_Mask.gbr, UHBadge-B_Paste.gbr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]
2026-09-22 Wrote the BOM.
    [UHBadge.csv]
2026-09-22 Fixed the BOM.
    [UHBadge.csv]
2026-09-22 Renamed the BOM.
    [BOM.csv]
2026-09-22 Fixed a detail.
    [UHBadge-B_Cu.gbr, UHBadge-B_Mask.gbr, UHBadge-B_Paste.gbr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]
2026-09-22 Compressed gerber files.
2026-09-29 Added the non-PCBA components to the BOM.
    [BOM.csv]
2026-09-29 Added all the links and prices to the BOM.
    [BOM.csv]
2026-09-29 Added the total.
    [BOM.csv]
2026-11-07 Moved the PCB in /PCB. Moved the step file in /CAD. Moved 3D model, gerber folder and firmware build in /production.
2026-11-10 Fix PCB link in README
2026-11-10 Added footprint positions file.

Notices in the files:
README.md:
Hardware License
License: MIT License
